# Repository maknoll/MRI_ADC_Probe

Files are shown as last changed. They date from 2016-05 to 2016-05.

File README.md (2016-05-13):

# STIMULATE MRI ADC Probe

This repository includes all hard- firm- and software resources realated to MRI ADC Probe developed for measuring gradient fields in a running MRI scanner. It is theoretically possible to sample 4 channels at 4.8Msps, however, at the moment it is limited to 2 channels at 200ksps due to bandwith limitations. Data is transmitted out of the MRI by consumer TOSLINK transmitters and optical fibre cable. 

## Hardware

The sampling Device is a STM32F303CCT6 ARM Cortex-M4 microprocessor. It was chosen for its 4 integrated operational Amplifiers, configured for offsetting, amplifying and buffering the input signals. It also features 4 high speed ADCs, multiple DMA channels and a DSP-like instruction set.

## Firmware

The firmware is inteded to sample continiusly, copy the samples from the ADCs to buffers with DMA and push them out of the UART as fast as possible.

## Software

The software receives data through a high-speed FT2232H USB Serial Interface and decodes the channels using a state machine. Samples for each channel are written to there subsequent files.

## Installation

### Dependencies

Developement machines should be configured with:

- libFTDI > 1.0
- a arm-none-eabi toolchain with gdb
- Eclipse
- the gnuarmeclipse plugin
- the STM32CubeMX eclipse plugin
- Kicad > 4.0, if hardware needs to be modified

### Setup

_The gnuarmeclipse Environment might has to be configured. This should be easiest by first creating a dummy project following the tutotials and making sure it works before continuing._

Import projects into Eclipse using the "Import -> Existing Projects into Workspace" Dialog.

The project template generator STM32CubeMX can be used directly from Eclipse by opening the firmware.ioc file. It is however standalone Software and has to be configured seperately to output generated code into the _firmware_ folder. This might or might not be the case after installation.

The Kicad project is opened by simply loading the ADC.pro file.

## Usage

If the probe is connected to the antennas and powered with ~5V, it outputs samples continously. To read and save them, the software has to be started on the host connected to the FT223H via USB. Filename prefixes can be chosen with the -f option. The software is stopped by hitting ctr-c.

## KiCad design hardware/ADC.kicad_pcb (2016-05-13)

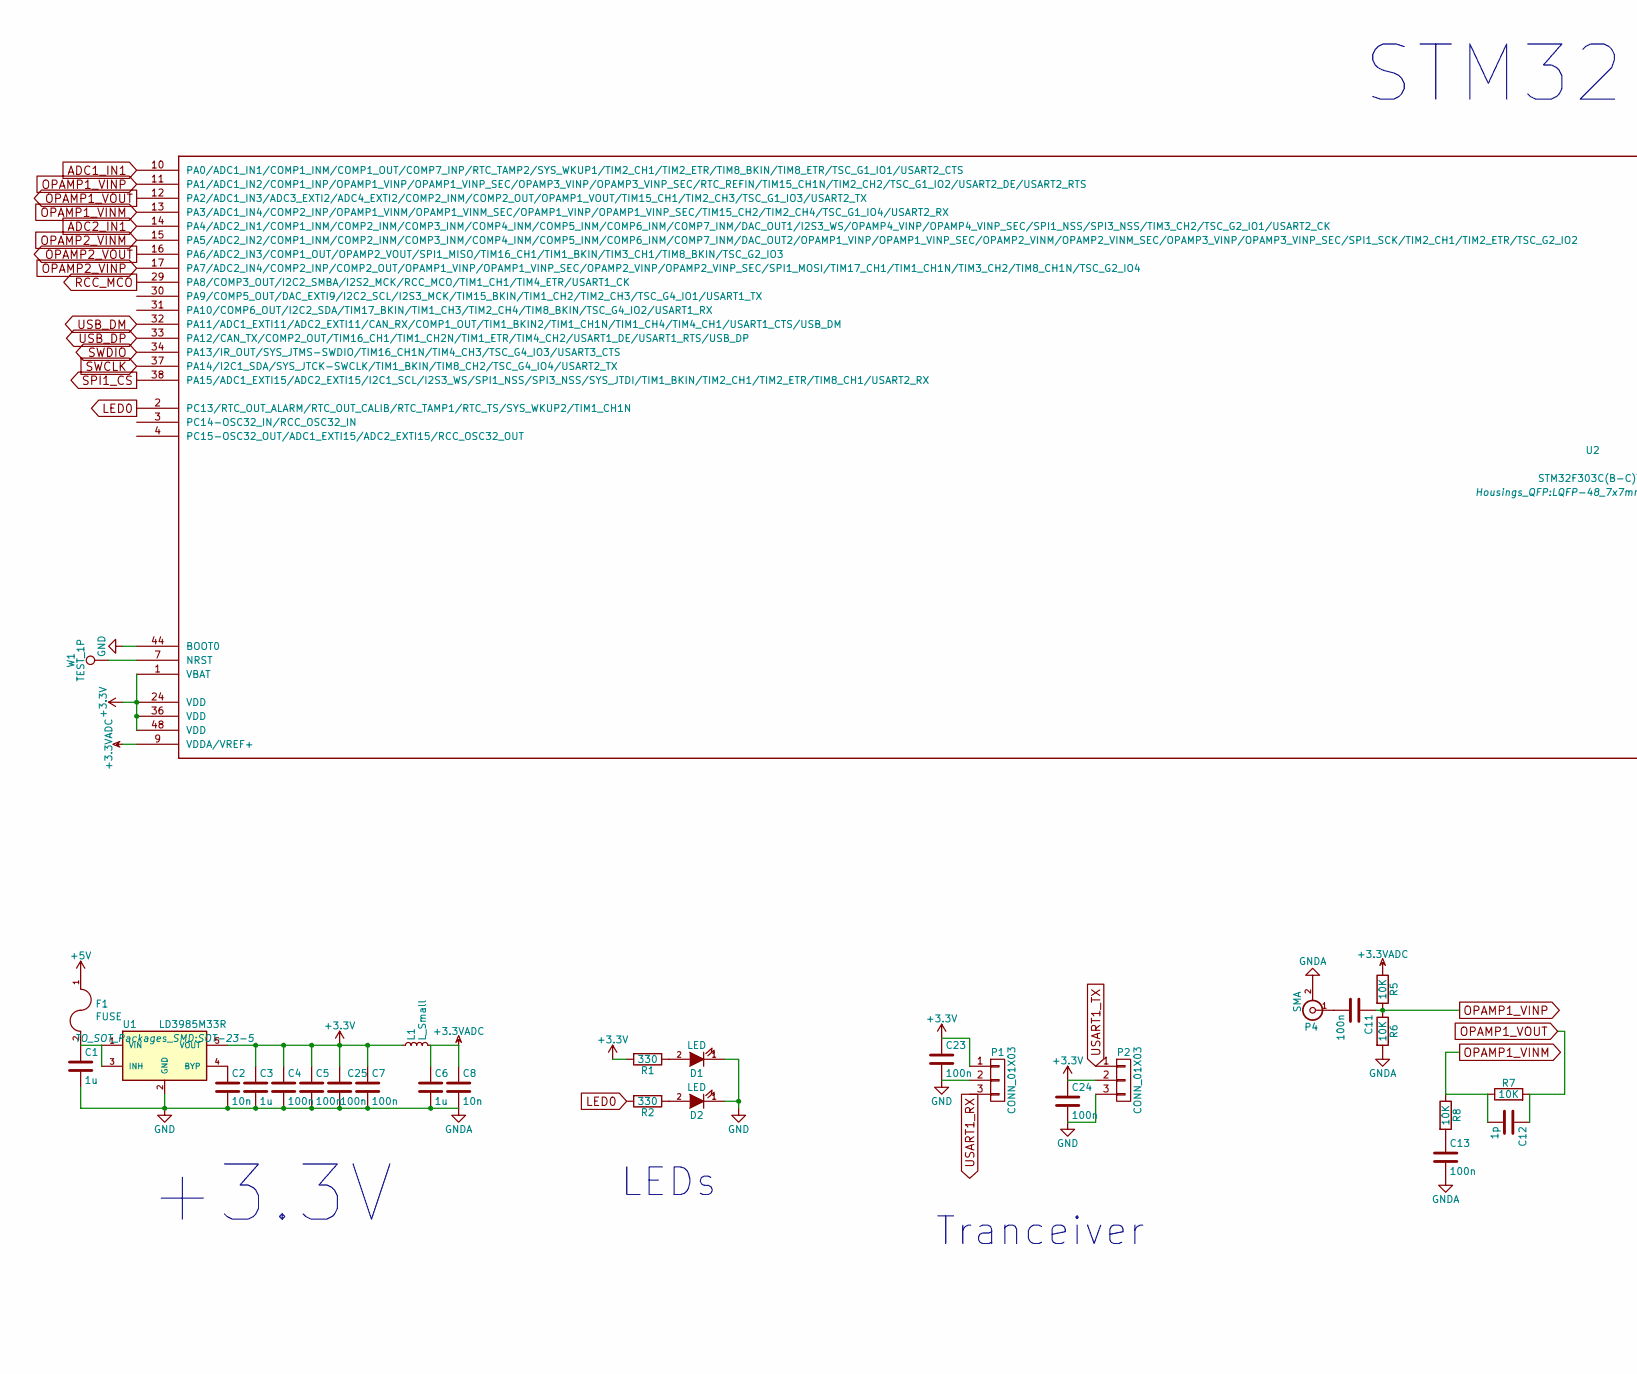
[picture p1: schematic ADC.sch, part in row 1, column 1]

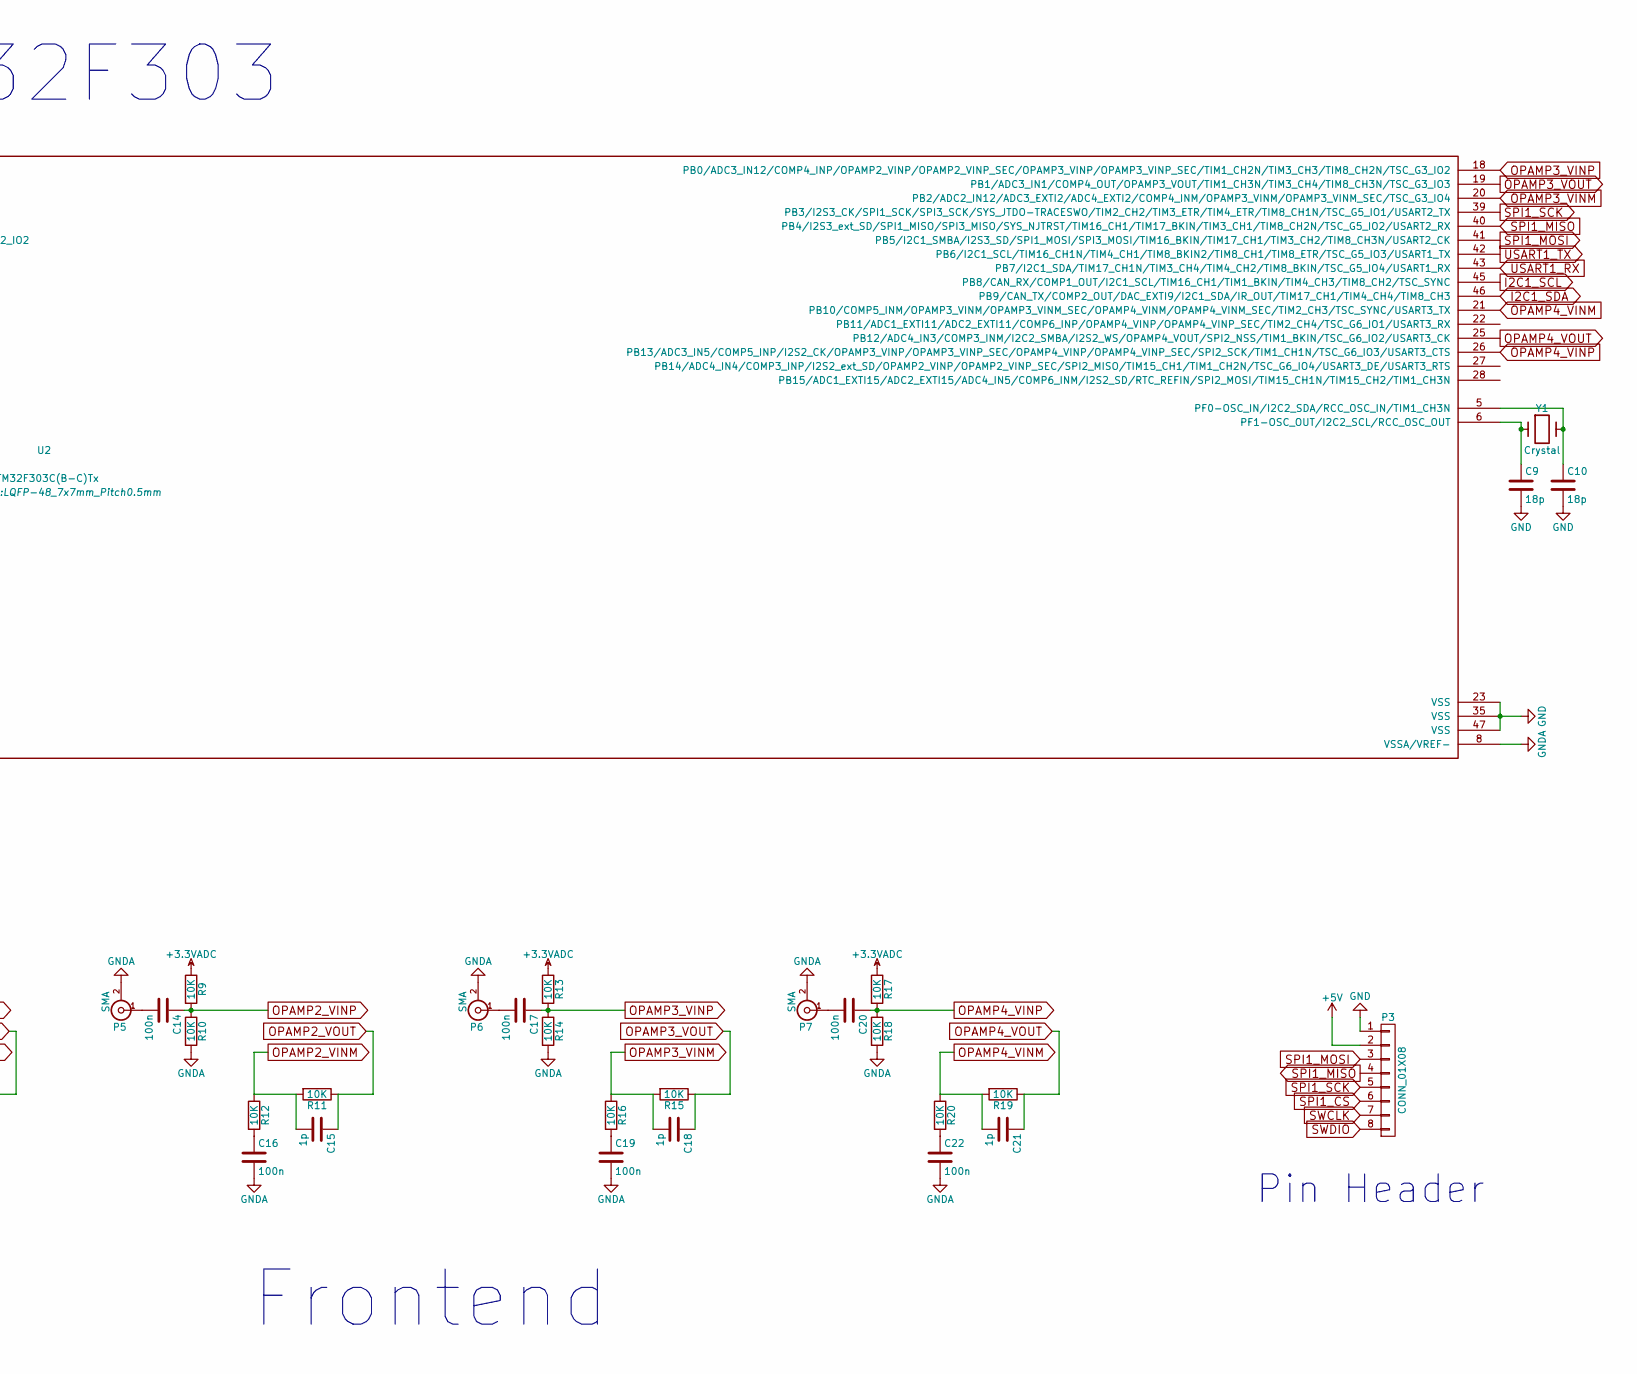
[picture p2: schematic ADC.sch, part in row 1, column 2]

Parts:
C1, C3, C6: 1u; C_0603
C2, C8: 10n; C_0603
C4, C5, C7, C11, C13, C14, C16, C17, C19, C20, C22, C23, C24, C25: 100n; C_0603
C9, C10: 18p; C_0603
C12, C15, C18, C21: 1p; C_0603
D1, D2: LED; LED_0603
F1: FUSE; Fuse_SMD1206_Reflow
L1: L_Small; R_0603
P1, P2: CONN_01X03; Toslink Tranceiver
P3: CONN_01X08; Pin_Header_Straight_1x08
P4, P5, P6, P7: SMA; SMA-ThroughHole
R1, R2: 330; R_0603
R5, R6, R7, R8, R9, R10, R11, R12, R13, R14, R15, R16, R17, R18, R19, R20: 10K; R_0603
U1: LD3985M33R; SOT-23-5; Part Number LD3985M33R
U2: STM32F303C(B-C)Tx; LQFP-48_7x7mm_Pitch0.5mm; Part Number STM32F303CCT6
W1: TEST_1P; Measurement_Point_Round-SMD-Pad_Small
Y1: Crystal; ABM3

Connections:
+3.3VADC: C6.1, C8.1, L1.2, R5.1, R9.1, R13.1, R17.1, U2.9 (VDDA/VREF+)
+3V3: C3.1, C4.1, C5.1, C7.1, C23.1, C24.1, C25.1, L1.1, P1.1, P2.2, R1.2, U1.5 (VOUT), U2.1 (VBAT), U2.24 (VDD), U2.36 (VDD), U2.48 (VDD)
+5V: F1.1, P3.2
ADC1_IN1: U2.10 (PA0/ADC1_IN1/COMP1_INM/COMP1_OUT/COMP7_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)
ADC2_IN1: U2.14 (PA4/ADC2_IN1/COMP1_INM/COMP2_INM/COMP3_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)
GND: C1.2, C2.2, C3.2, C4.2, C5.2, C6.2, C7.2, C8.2, C9.2, C10.2, C13.2, C16.2, C19.2, C22.2, C23.2, C24.2, C25.2, D1.1 (K), D2.1 (K), P1.2, P2.3, P3.1, P4.2 (Ext), P5.2 (Ext), P6.2 (Ext), P7.2 (Ext), R6.2, R10.2, R14.2, R18.2, U1.2 (GND), U2.8 (VSSA/VREF-), U2.23 (VSS), U2.35 (VSS), U2.44 (BOOT0), U2.47 (VSS)
I2C1_SCL: U2.45 (PB8/CAN_RX/COMP1_OUT/I2C1_SCL/TIM16_CH1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)
I2C1_SDA: U2.46 (PB9/CAN_TX/COMP2_OUT/DAC_EXTI9/I2C1_SDA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)
LED0: R2.2, U2.2 (PC13/RTC_OUT_ALARM/RTC_OUT_CALIB/RTC_TA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)
unnamed: C1.1, F1.2, U1.1 (VIN), U1.3 (INH)
unnamed: C2.1, U1.4 (BYP)
unnamed: C9.1, U2.6 (PF1-OSC_OUT/I2C2_SCL/RCC_OSC_OUT), Y1.1
unnamed: C10.1, U2.5 (PF0-OSC_IN/I2C2_SDA/RCC_OSC_IN/TIM1_CH3N), Y1.2
unnamed: C11.2, P4.1 (In)
unnamed: C13.1, R8.2
unnamed: C14.2, P5.1 (In)
unnamed: C16.1, R12.2
unnamed: C17.2, P6.1 (In)
unnamed: C19.1, R16.2
unnamed: C20.2, P7.1 (In)
unnamed: C22.1, R20.2
unnamed: D1.2 (A), R1.1
unnamed: D2.2 (A), R2.1
unnamed: U2.7 (NRST), W1.1
OPAMP1_VINM: C12.2, R7.1, R8.1, U2.13 (PA3/ADC1_IN4/COMP2_INP/OPAMP1_VINM/OPAM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)
OPAMP1_VINP: C11.1, R5.2, R6.1, U2.11 (PA1/ADC1_IN2/COMP1_INP/OPAMP1_VINP/OPAM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)
OPAMP1_VOUT: C12.1, R7.2, U2.12 (PA2/ADC1_IN3/ADC3_EXTI2/ADC4_EXTI2/COMP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)
OPAMP2_VINM: C15.2, R11.2, R12.1, U2.15 (PA5/ADC2_IN2/COMP1_INM/COMP2_INM/COMP3_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)
OPAMP2_VINP: C14.1, R9.2, R10.1, U2.17 (PA7/ADC2_IN4/COMP2_INP/COMP2_OUT/OPAMP1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)
OPAMP2_VOUT: C15.1, R11.1, U2.16 (PA6/ADC2_IN3/COMP1_OUT/OPAMP2_VOUT/SPI1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)
OPAMP3_VINM: C18.2, R15.2, R16.1, U2.20 (PB2/ADC2_IN12/ADC3_EXTI2/ADC4_EXTI2/COM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)
OPAMP3_VINP: C17.1, R13.2, R14.1, U2.18 (PB0/ADC3_IN12/COMP4_INP/OPAMP2_VINP/OPA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)
OPAMP3_VOUT: C18.1, R15.1, U2.19 (PB1/ADC3_IN1/COMP4_OUT/OPAMP3_VOUT/TIM1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)
OPAMP4_VINM: C21.2, R19.2, R20.1, U2.21 (PB10/COMP5_INM/OPAMP3_VINM/OPAMP3_VINM_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)
OPAMP4_VINP: C20.1, R17.2, R18.1, U2.26 (PB13/ADC3_IN5/COMP5_INP/I2S2_CK/OPAMP3_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)
OPAMP4_VOUT: C21.1, R19.1, U2.25 (PB12/ADC4_IN3/COMP3_INM/I2C2_SMBA/I2S2_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)
RCC_MCO: U2.29 (PA8/COMP3_OUT/I2C2_SMBA/I2S2_MCK/RCC_MC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)
SPI1_CS: P3.6, U2.38 (PA15/ADC1_EXTI15/ADC2_EXTI15/I2C1_SCL/I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)
SPI1_MISO: P3.4, U2.40 (PB4/I2S3_ext_SD/SPI1_MISO/SPI3_MISO/SYS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)
SPI1_MOSI: P3.3, U2.41 (PB5/I2C1_SMBA/I2S3_SD/SPI1_MOSI/SPI3_MO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)
SPI1_SCK: P3.5, U2.39 (PB3/I2S3_CK/SPI1_SCK/SPI3_SCK/SYS_JTDO-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)
SWCLK: P3.7, U2.37 (PA14/I2C1_SDA/SYS_JTCK-SWCLK/TIM1_BKIN/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)
SWDIO: P3.8, U2.34 (PA13/IR_OUT/SYS_JTMS-SWDIO/TIM16_CH1N/T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)
USART1_RX: P1.3, U2.43 (PB7/I2C1_SDA/TIM17_CH1N/TIM3_CH4/TIM4_C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)
USART1_TX: P2.1, U2.42 (PB6/I2C1_SCL/TIM16_CH1N/TIM4_CH1/TIM8_B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)
USB_DM: U2.32 (PA11/ADC1_EXTI11/ADC2_EXTI11/CAN_RX/COM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)
USB_DP: U2.33 (PA12/CAN_TX/COMP2_OUT/TIM16_CH1/TIM1_CH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)

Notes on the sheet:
Frontend
+3.3V
Tranceiver
LEDs
STM32F303
Pin Header

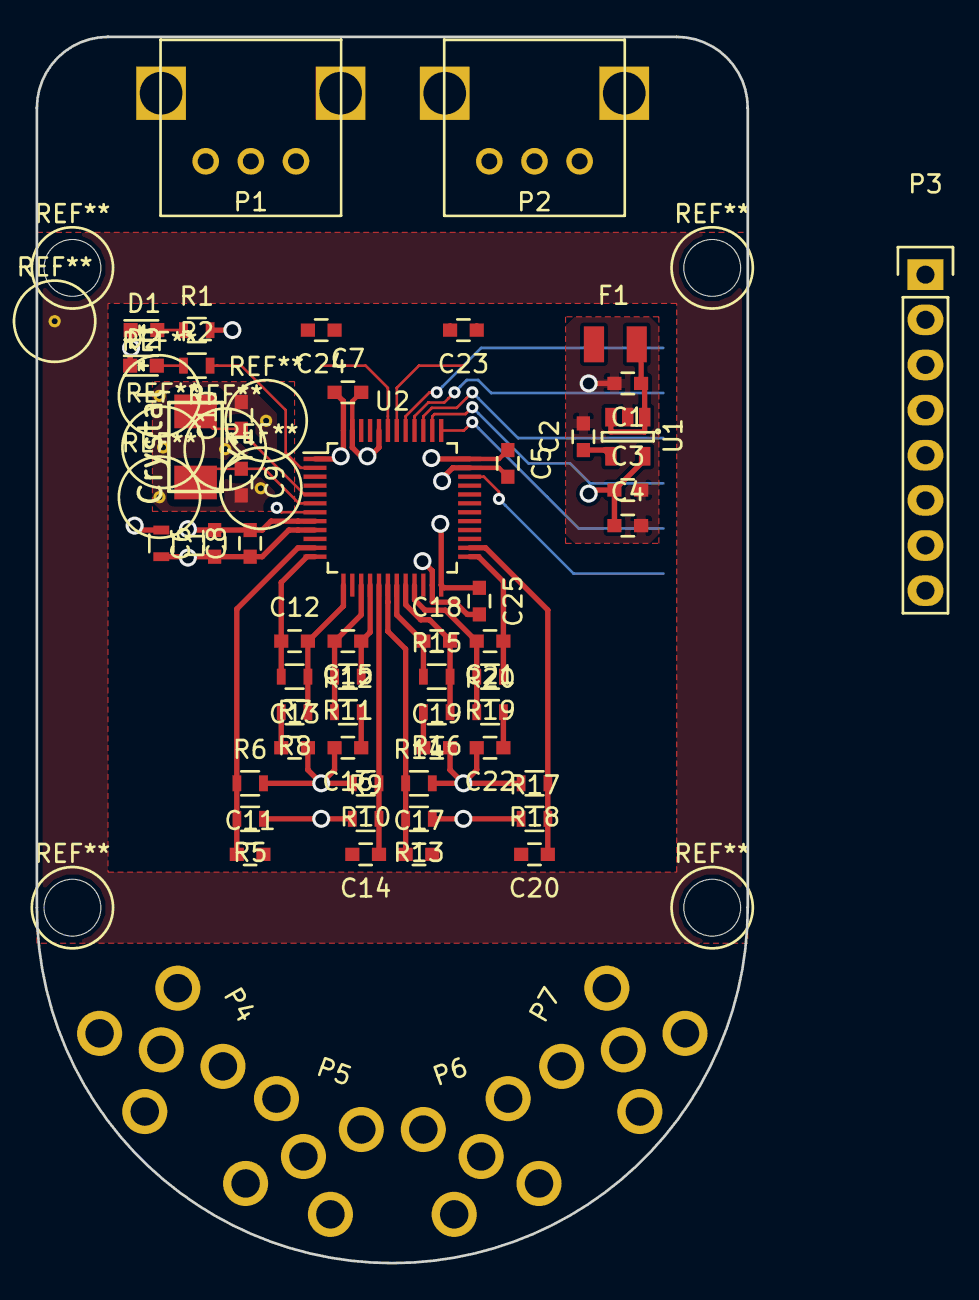
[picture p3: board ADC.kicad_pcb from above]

Board: 4 copper layers, 40.0 x 69.0 mm, 58 parts (1 on the bottom side), 40 nets.

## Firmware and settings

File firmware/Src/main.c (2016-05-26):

/**
  ******************************************************************************
  * File Name          : main.c
  * Description        : Main program body
  ******************************************************************************
  *
  * COPYRIGHT(c) 2016 STMicroelectronics
  *
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
  ******************************************************************************
  */
/* Includes ------------------------------------------------------------------*/
#include "stm32f3xx_hal.h"
#include "adc.h"
#include "dma.h"
#include "opamp.h"
#include "spi.h"
#include "tim.h"
#include "usart.h"
#include "gpio.h"

/* USER CODE BEGIN Includes */
#include <string.h>
/* USER CODE END Includes */


/* USER CODE BEGIN PV */

struct ADC_Packet{
	uint32_t preamble;
	uint16_t channel;
	uint16_t buffer[1001];
};

#define PREAMBLE 0xFFFFF0F0

struct __attribute__((packed)) ADC_Packet ADC1_Packet = {PREAMBLE,1,{0}};
struct __attribute__((packed)) ADC_Packet ADC2_Packet = {PREAMBLE,2,{0}};
struct __attribute__((packed)) ADC_Packet ADC3_Packet = {PREAMBLE,3,{0}};
struct __attribute__((packed)) ADC_Packet ADC4_Packet = {PREAMBLE,4,{0}};

uint8_t ADC_doublebufferbit[4] = {0};
uint8_t ADC1_doublebuffer[2][2000] = {{0},{0}};
uint8_t ADC2_doublebuffer[2][2000] = {{0},{0}};
uint8_t ADC3_doublebuffer[2][2000] = {{0},{0}};
uint8_t ADC4_doublebuffer[2][2000] = {{0},{0}};

extern const unsigned short me_encode_tab[];
/* USER CODE END PV */

void SystemClock_Config(void);

/* USER CODE BEGIN PFP */

/* USER CODE END PFP */

/* USER CODE BEGIN 0 */

void me_encode(uint8_t raw[],uint16_t encoded[], uint16_t length)
{
	for (int i = 0; i < length; i++) {
		encoded[i] = me_encode_tab[raw[i]];
	}
}

void HAL_UART_TxCpltCallback(UART_HandleTypeDef* huart)
{
//	__HAL_UART_SEND_REQ(&huart1 ,UART_SENDBREAK_REQUEST);
}

void HAL_ADC_ConvCpltCallback(ADC_HandleTypeDef* hadc)
{
	HAL_ADC_Stop(hadc);
	if (&hadc1 == hadc) {
		//me_encode(ADC1_doublebuffer[ADC_doublebufferbit[0]],ADC1_Packet.buffer, 2000);
		//ADC_doublebufferbit[0] = ADC_doublebufferbit[0] ? 0 : 1;
		HAL_UART_Transmit_DMA(&huart1, (uint8_t*)&ADC1_Packet, sizeof(struct ADC_Packet));
	}
	if (&hadc4 == hadc) {
		//me_encode(ADC4_doublebuffer[ADC_doublebufferbit[3]],ADC4_Packet.buffer, 2000);
		//ADC_doublebufferbit[3] = ADC_doublebufferbit[3] ? 0 : 1;
		HAL_UART_Transmit_DMA(&huart1, (uint8_t*)&ADC4_Packet, sizeof(struct ADC_Packet));
	}
}

void HAL_ADC_ConvHalfCpltCallback(ADC_HandleTypeDef* hadc)
{
	if (&hadc1 == hadc) {
		HAL_ADC_Start_DMA(&hadc4, (uint32_t*)ADC4_Packet.buffer, 1000);
	}
	if (&hadc4 == hadc) {
		HAL_ADC_Start_DMA(&hadc1, (uint32_t*)ADC1_Packet.buffer, 1000);
	}
}

/* USER CODE END 0 */

int main(void)
{

  /* MCU Configuration----------------------------------------------------------*/

  /* Reset of all peripherals, Initializes the Flash interface and the Systick. */
  HAL_Init();

  /* Configure the system clock */
  SystemClock_Config();

  /* Initialize all configured peripherals */
  MX_GPIO_Init();
  MX_DMA_Init();
  MX_ADC1_Init();
  MX_OPAMP1_Init();
  MX_OPAMP2_Init();
  MX_OPAMP3_Init();
  MX_OPAMP4_Init();
  MX_USART1_UART_Init();
  MX_ADC4_Init();
  MX_SPI1_Init();
  MX_TIM3_Init();

  /* USER CODE BEGIN 2 */
  HAL_StatusTypeDef HAL_Status;

  HAL_Status = HAL_TIM_Base_Start(&htim3);
    if (HAL_Status != HAL_OK)
  	  return 0;
  HAL_ADC_Stop_DMA(&hadc1);
  //  HAL_ADC_Stop_DMA(&hadc2);
  //  HAL_ADC_Stop_DMA(&hadc3);
  HAL_ADC_Stop_DMA(&hadc4);

  HAL_Status = HAL_ADCEx_Calibration_SetValue(&hadc1, ADC_SINGLE_ENDED, 0);
  if (HAL_Status != HAL_OK)
	  return 0;
  HAL_Status = HAL_OPAMP_Start(&hopamp1);
  if (HAL_Status != HAL_OK)
	  return 0;

  HAL_Status = HAL_ADCEx_Calibration_SetValue(&hadc4, ADC_SINGLE_ENDED, 0);
    if (HAL_Status != HAL_OK)
  	  return 0;
    HAL_Status = HAL_OPAMP_Start(&hopamp4);
    if (HAL_Status != HAL_OK)
  	  return 0;

  HAL_StatusTypeDef ADC_DMA_Status = HAL_ADC_Start_DMA(&hadc1, (uint32_t*)ADC1_Packet.buffer, 1000);
  if (ADC_DMA_Status != HAL_OK)
	  return 0;

  /* USER CODE END 2 */

  /* Infinite loop */
  /* USER CODE BEGIN WHILE */
  while (1)
  {
  /* USER CODE END WHILE */

  /* USER CODE BEGIN 3 */
	  HAL_PWR_EnterSLEEPMode(PWR_MAINREGULATOR_ON, PWR_SLEEPENTRY_WFI);
  }
  /* USER CODE END 3 */

}

/** System Clock Configuration
*/
void SystemClock_Config(void)
{

  RCC_OscInitTypeDef RCC_OscInitStruct;
  RCC_ClkInitTypeDef RCC_ClkInitStruct;
  RCC_PeriphCLKInitTypeDef PeriphClkInit;

  RCC_OscInitStruct.OscillatorType = RCC_OSCILLATORTYPE_HSE;
  RCC_OscInitStruct.HSEState = RCC_HSE_ON;
  RCC_OscInitStruct.HSEPredivValue = RCC_HSE_PREDIV_DIV1;
  RCC_OscInitStruct.PLL.PLLState = RCC_PLL_ON;
  RCC_OscInitStruct.PLL.PLLSource = RCC_PLLSOURCE_HSE;
  RCC_OscInitStruct.PLL.PLLMUL = RCC_PLL_MUL8;
  HAL_RCC_OscConfig(&RCC_OscInitStruct);

  RCC_ClkInitStruct.ClockType = RCC_CLOCKTYPE_HCLK|RCC_CLOCKTYPE_SYSCLK
                              |RCC_CLOCKTYPE_PCLK1|RCC_CLOCKTYPE_PCLK2;
  RCC_ClkInitStruct.SYSCLKSource = RCC_SYSCLKSOURCE_PLLCLK;
  RCC_ClkInitStruct.AHBCLKDivider = RCC_SYSCLK_DIV1;
  RCC_ClkInitStruct.APB1CLKDivider = RCC_HCLK_DIV2;
  RCC_ClkInitStruct.APB2CLKDivider = RCC_HCLK_DIV1;
  HAL_RCC_ClockConfig(&RCC_ClkInitStruct, FLASH_LATENCY_2);

  PeriphClkInit.PeriphClockSelection = RCC_PERIPHCLK_USART1;
  PeriphClkInit.Usart1ClockSelection = RCC_USART1CLKSOURCE_SYSCLK;
  HAL_RCCEx_PeriphCLKConfig(&PeriphClkInit);

  HAL_SYSTICK_Config(HAL_RCC_GetHCLKFreq()/1000);

  HAL_SYSTICK_CLKSourceConfig(SYSTICK_CLKSOURCE_HCLK);

  /* SysTick_IRQn interrupt configuration */
  HAL_NVIC_SetPriority(SysTick_IRQn, 0, 0);
}

#ifdef USE_FULL_ASSERT

/**
   * @brief Reports the name of the source file and the source line number
   * where the assert_param error has occurred.
   * @param file: pointer to the source file name
   * @param line: assert_param error line source number
   * @retval None
   */
void assert_failed(uint8_t* file, uint32_t line)
{
  /* USER CODE BEGIN 6 */
  /* User can add his own implementation to report the file name and line number,
    ex: printf("Wrong parameters value: file %s on line %d\r\n", file, line) */
  /* USER CODE END 6 */

}

#endif

/**
  * @}
  */ 

/**
  * @}
*/ 

/************************ (C) COPYRIGHT STMicroelectronics *****END OF FILE****/

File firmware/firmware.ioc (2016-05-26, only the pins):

Mcu.UserName=STM32F303CCTx
PA1.Signal=OPAMP1_VINP
PA13.Signal=SYS_JTMS-SWDIO
PA14.Signal=SYS_JTCK-SWCLK
PA2.Signal=OPAMP1_VOUT
PA3.Signal=OPAMP1_VINM
PA5.Signal=OPAMP2_VINM
PA6.Signal=OPAMP2_VOUT
PA7.Signal=OPAMP2_VINP
PB0.Signal=OPAMP3_VINP
PB1.Signal=OPAMP3_VOUT
PB10.Signal=OPAMP4_VINM
PB12.Signal=OPAMP4_VOUT
PB13.Signal=OPAMP4_VINP
PB2.Signal=OPAMP3_VINM
PB3.Signal=SPI1_SCK
PB5.Signal=SPI1_MOSI
PB6.Signal=USART1_TX
PB7.Signal=USART1_RX
PC13.Signal=GPIO_Output
PF0-OSC_IN.Signal=RCC_OSC_IN
PF1-OSC_OUT.Signal=RCC_OSC_OUT
